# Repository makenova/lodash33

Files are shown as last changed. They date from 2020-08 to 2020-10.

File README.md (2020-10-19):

# lodash33
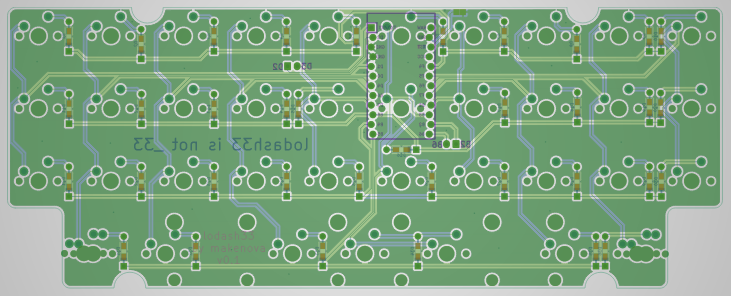
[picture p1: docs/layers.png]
layers


A promicro version of the _33 keyboard.  There are produciton files in the "gerbers" directory for the pcb and a skeleton case.
Simply upload the zip files to your PCB manufacturer of choice.

You'll also need

* Diodes (1N4148W)
  * Through hole or SMD(sod-123). Either will work
* Pro Micro(PM) or compatible board
  * I prefer something with USB C
  * You can use a nice!nano if you want to make it wireless
* Hardware
  * M2 screws
  * M2 standoffs(10mm will work if solder your PM directly or socket with low profile sockets use 12mm to be safe)

There are at least two possible layouts

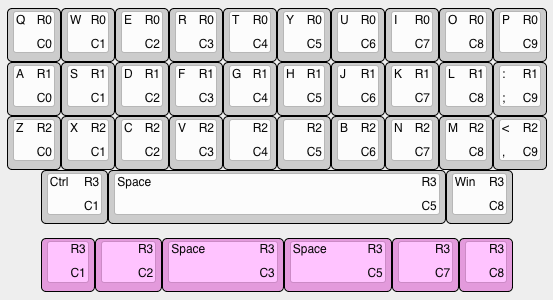
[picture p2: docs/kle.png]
KLE Diagram


Starting firmware can be found on my QMK fork in the [`makenova`](https://github.com/makenova/qmk_firmware/tree/makenova/keyboards/makenova/lodash33) branch.

Here is what a built version can look like:  

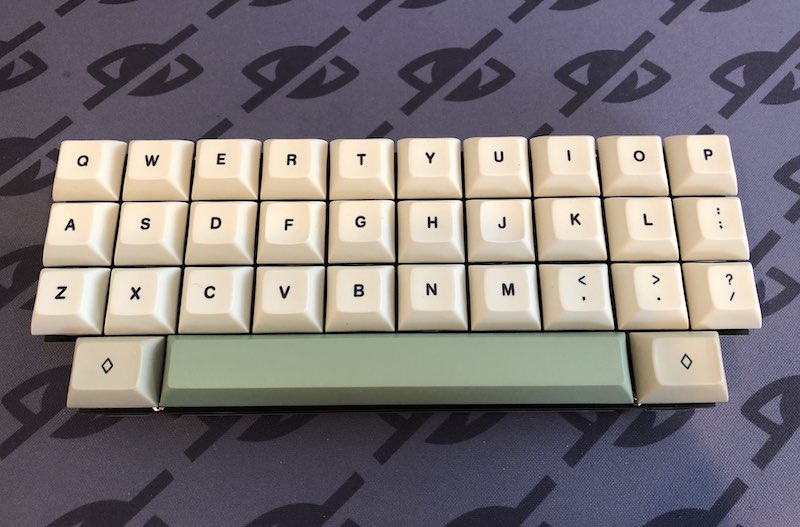
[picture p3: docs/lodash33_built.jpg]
built


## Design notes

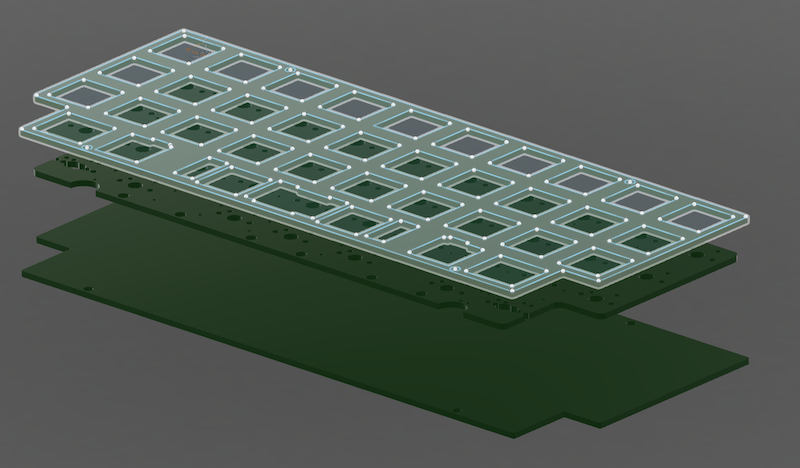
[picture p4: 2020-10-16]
docs/Screen Shot 2020-08-13 at 8.09.08 PM.png

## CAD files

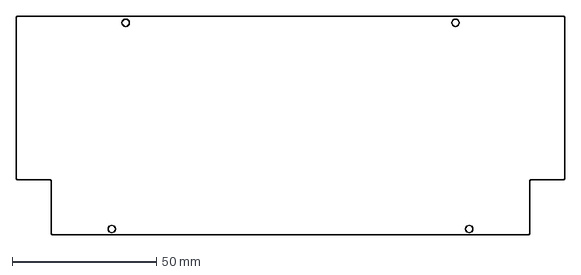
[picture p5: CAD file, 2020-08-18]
33_bottom_plate.dxf
190.0 x 75.7 mm

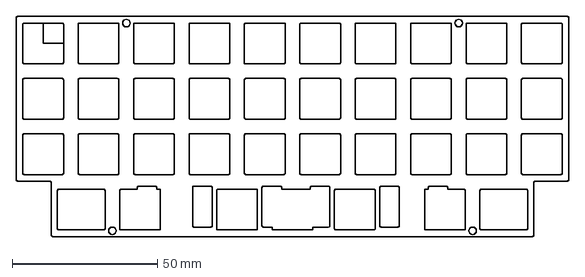
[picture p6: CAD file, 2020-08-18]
docs/_33_plate.dxf
190.0 x 75.7 mm

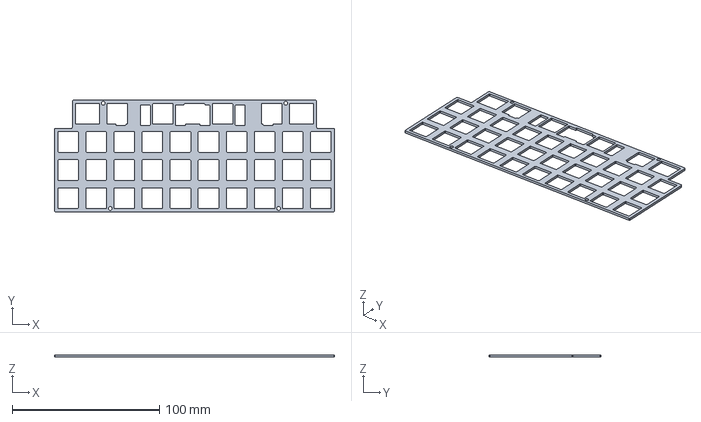
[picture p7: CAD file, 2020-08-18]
33_plate.step
190.0 x 75.7 x 1.60 mm

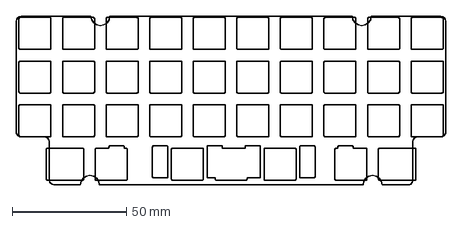
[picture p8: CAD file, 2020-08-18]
docs/pcb_outline.dxf
187.7 x 73.8 mm

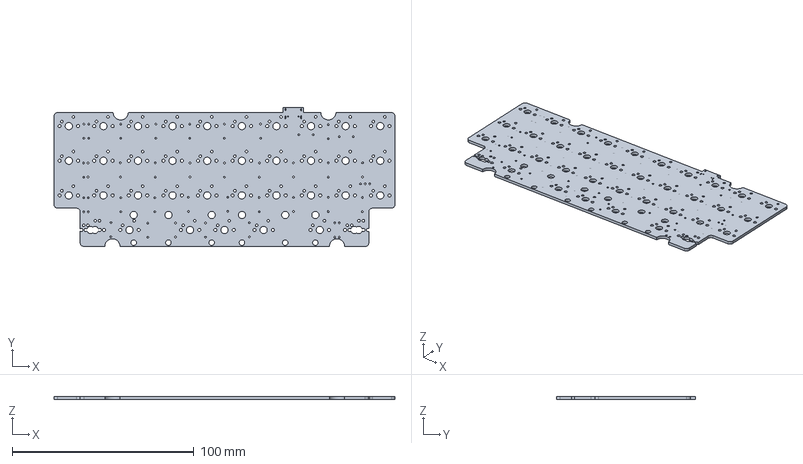
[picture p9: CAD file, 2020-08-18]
33.stp
187.7 x 76.5 x 1.60 mm

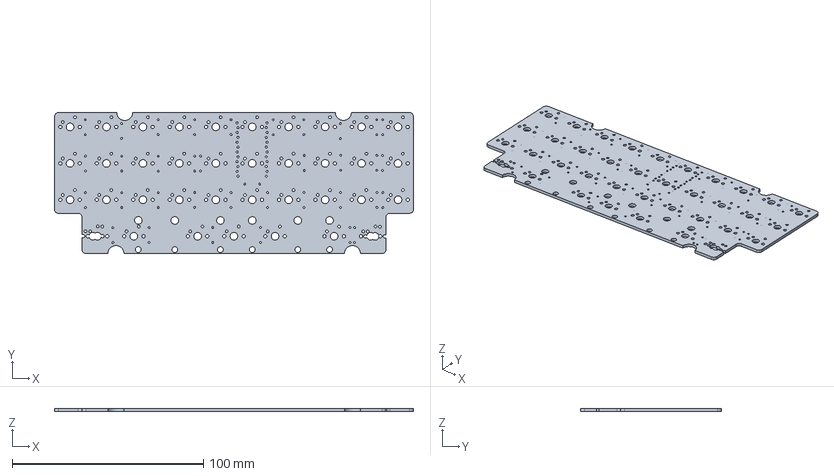
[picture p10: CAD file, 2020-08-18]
docs/33.step
187.7 x 73.8 x 1.60 mm

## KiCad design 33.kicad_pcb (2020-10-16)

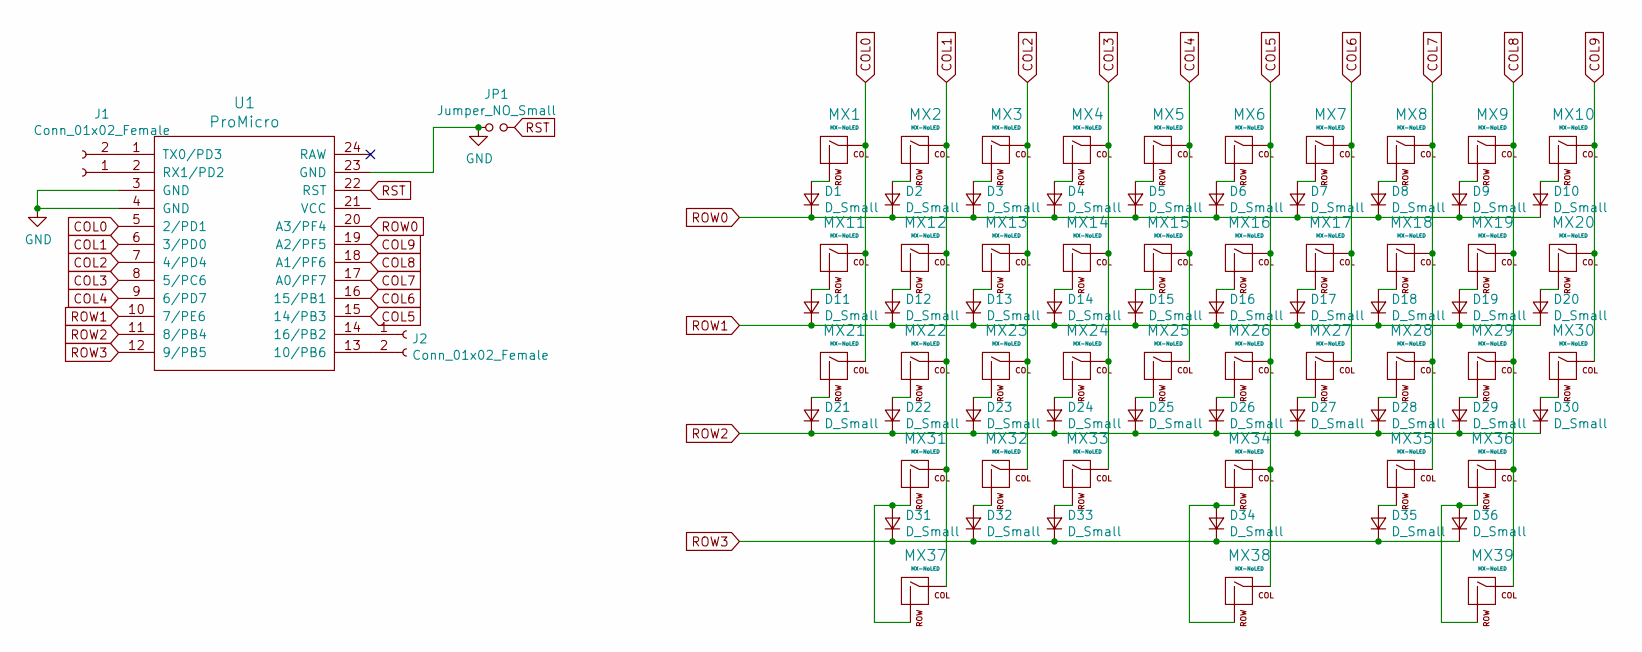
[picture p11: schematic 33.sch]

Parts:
D1, D2, D3, D4, D5, D6, D7, D8, D9, D10, D11, D12, D13, D14, D15, D16, D17, D18, D19, D20, D21, D22, D23, D24, D25, D26, D27, D28, D29, D30, D31, D32, D33, D34, D35, D36: D_Small; Diode-Hybrid-Back
J1, J2: Conn_01x02_Female; JST_EH_B2B-EH-A_1x02_P2.50mm_Vertical
JP1: Jumper_NO_Small; Jumper-UserFriendly-Small
MX1, MX2, MX3, MX4, MX5, MX6, MX7, MX8, MX9, MX10, MX11, MX12, MX13, MX14, MX15, MX16, MX17, MX18, MX19, MX20, MX21, MX22, MX23, MX24, MX25, MX26, MX27, MX28, MX29, MX30, MX31, MX36, MX39: MX-NoLED; MXOnly-1U-NoLED
MX32, MX35, MX37: MX-NoLED; MXOnly-1.25U-NoLED
MX33: MX-NoLED; MXOnly-2.25U-ReversedStabilizers-NoLED
MX34: MX-NoLED; MXOnly-2U-ReversedStabilizers-NoLED
MX38: MX-NoLED; MXOnly-6.25U-ReversedStabilizers-NoLED
U1: ProMicro; ArduinoProMicro-ZigZag

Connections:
COL0: MX1.1 (COL), MX11.1 (COL), MX21.1 (COL), U1.5 (2/PD1)
COL1: MX2.1 (COL), MX12.1 (COL), MX22.1 (COL), MX31.1 (COL), MX37.1 (COL), U1.6 (3/PD0)
COL2: MX3.1 (COL), MX13.1 (COL), MX23.1 (COL), MX32.1 (COL), U1.7 (4/PD4)
COL3: MX4.1 (COL), MX14.1 (COL), MX24.1 (COL), MX33.1 (COL), U1.8 (5/PC6)
COL4: MX5.1 (COL), MX15.1 (COL), MX25.1 (COL), U1.9 (6/PD7)
COL5: MX6.1 (COL), MX16.1 (COL), MX26.1 (COL), MX34.1 (COL), MX38.1 (COL), U1.15 (14/PB3)
COL6: MX7.1 (COL), MX17.1 (COL), MX27.1 (COL), U1.16 (15/PB1)
COL7: MX8.1 (COL), MX18.1 (COL), MX28.1 (COL), MX35.1 (COL), U1.17 (A0/PF7)
COL8: MX9.1 (COL), MX19.1 (COL), MX29.1 (COL), MX36.1 (COL), MX39.1 (COL), U1.18 (A1/PF6)
COL9: MX10.1 (COL), MX20.1 (COL), MX30.1 (COL), U1.19 (A2/PF5)
GND: JP1.1, U1.3 (GND), U1.4 (GND), U1.23 (GND)
unnamed: D1.2 (A), MX1.2 (ROW)
unnamed: D2.2 (A), MX2.2 (ROW)
unnamed: D3.2 (A), MX3.2 (ROW)
unnamed: D4.2 (A), MX4.2 (ROW)
unnamed: D5.2 (A), MX5.2 (ROW)
unnamed: D6.2 (A), MX6.2 (ROW)
unnamed: D7.2 (A), MX7.2 (ROW)
unnamed: D8.2 (A), MX8.2 (ROW)
unnamed: D9.2 (A), MX9.2 (ROW)
unnamed: D10.2 (A), MX10.2 (ROW)
unnamed: D11.2 (A), MX11.2 (ROW)
unnamed: D12.2 (A), MX12.2 (ROW)
unnamed: D13.2 (A), MX13.2 (ROW)
unnamed: D14.2 (A), MX14.2 (ROW)
unnamed: D15.2 (A), MX15.2 (ROW)
unnamed: D16.2 (A), MX16.2 (ROW)
unnamed: D17.2 (A), MX17.2 (ROW)
unnamed: D18.2 (A), MX18.2 (ROW)
unnamed: D19.2 (A), MX19.2 (ROW)
unnamed: D20.2 (A), MX20.2 (ROW)
unnamed: D21.2 (A), MX21.2 (ROW)
unnamed: D22.2 (A), MX22.2 (ROW)
unnamed: D23.2 (A), MX23.2 (ROW)
unnamed: D24.2 (A), MX24.2 (ROW)
unnamed: D25.2 (A), MX25.2 (ROW)
unnamed: D26.2 (A), MX26.2 (ROW)
unnamed: D27.2 (A), MX27.2 (ROW)
unnamed: D28.2 (A), MX28.2 (ROW)
unnamed: D29.2 (A), MX29.2 (ROW)
unnamed: D30.2 (A), MX30.2 (ROW)
unnamed: D31.2 (A), MX31.2 (ROW), MX37.2 (ROW)
unnamed: D32.2 (A), MX32.2 (ROW)
unnamed: D33.2 (A), MX33.2 (ROW)
unnamed: D34.2 (A), MX34.2 (ROW), MX38.2 (ROW)
unnamed: D35.2 (A), MX35.2 (ROW)
unnamed: D36.2 (A), MX36.2 (ROW), MX39.2 (ROW)
unnamed: J1.1, U1.2 (RX1/PD2)
unnamed: J1.2, U1.1 (TX0/PD3)
unnamed: J2.1, U1.14 (16/PB2)
unnamed: J2.2, U1.13 (10/PB6)
ROW0: D1.1 (K), D2.1 (K), D3.1 (K), D4.1 (K), D5.1 (K), D6.1 (K), D7.1 (K), D8.1 (K), D9.1 (K), D10.1 (K), U1.20 (A3/PF4)
ROW1: D11.1 (K), D12.1 (K), D13.1 (K), D14.1 (K), D15.1 (K), D16.1 (K), D17.1 (K), D18.1 (K), D19.1 (K), D20.1 (K), U1.10 (7/PE6)
ROW2: D21.1 (K), D22.1 (K), D23.1 (K), D24.1 (K), D25.1 (K), D26.1 (K), D27.1 (K), D28.1 (K), D29.1 (K), D30.1 (K), U1.11 (8/PB4)
ROW3: D31.1 (K), D32.1 (K), D33.1 (K), D34.1 (K), D35.1 (K), D36.1 (K), U1.12 (9/PB5)
RST: JP1.2, U1.22 (RST)

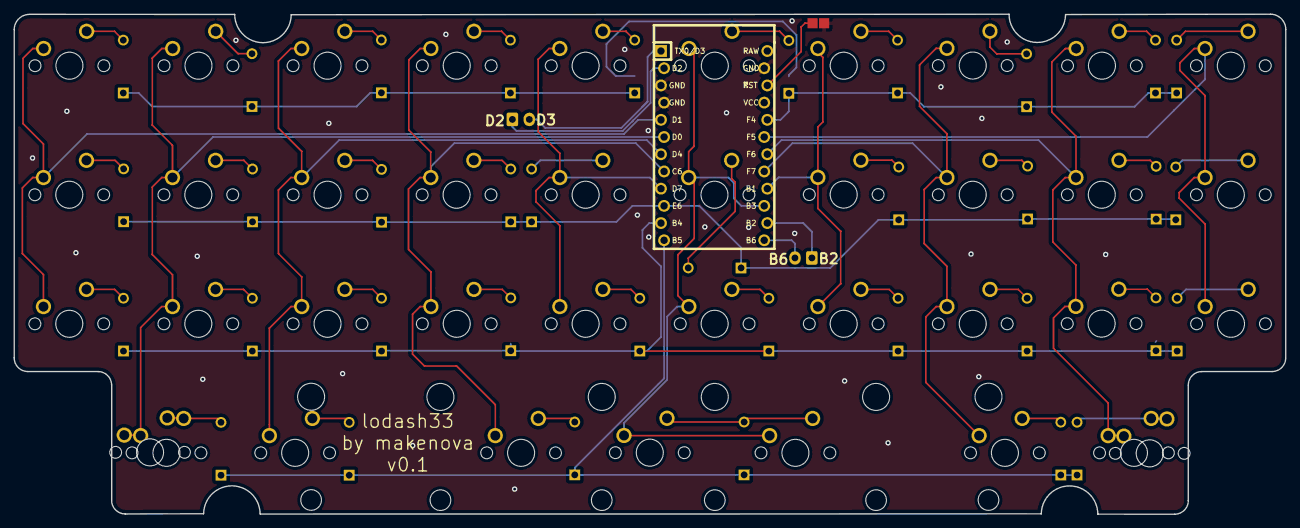
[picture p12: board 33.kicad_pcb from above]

Board: 2 copper layers, 187.7 x 73.8 mm, 79 parts (0 on the bottom side), 56 nets.

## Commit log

2020-08-18 make it so
    [33-B_Cu.gbr, 33-B_Mask.gbr, 33-B_Paste.gbr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]
2020-10-15 update reset jumper position
    [33-B_Cu.gbr, 33-B_Mask.gbr, 33-B_Paste.gbr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]
2020-10-16 breakout 4 unused pins
    [33-B_Cu.gbr, 33-B_Mask.gbr, 33-B_Paste.gbr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]
